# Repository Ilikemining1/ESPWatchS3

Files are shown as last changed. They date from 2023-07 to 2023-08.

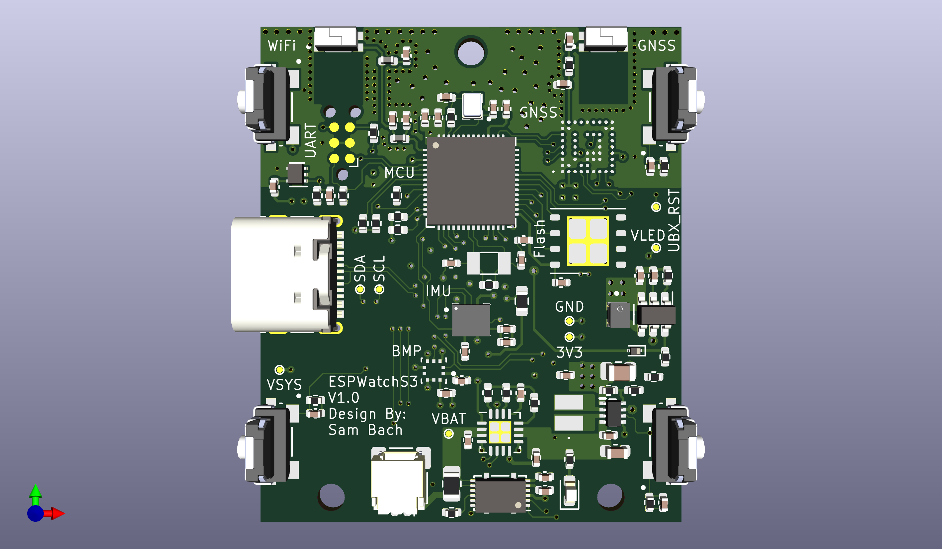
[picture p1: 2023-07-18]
PCB Outputs/ESPWatchS3 PCB Front.png

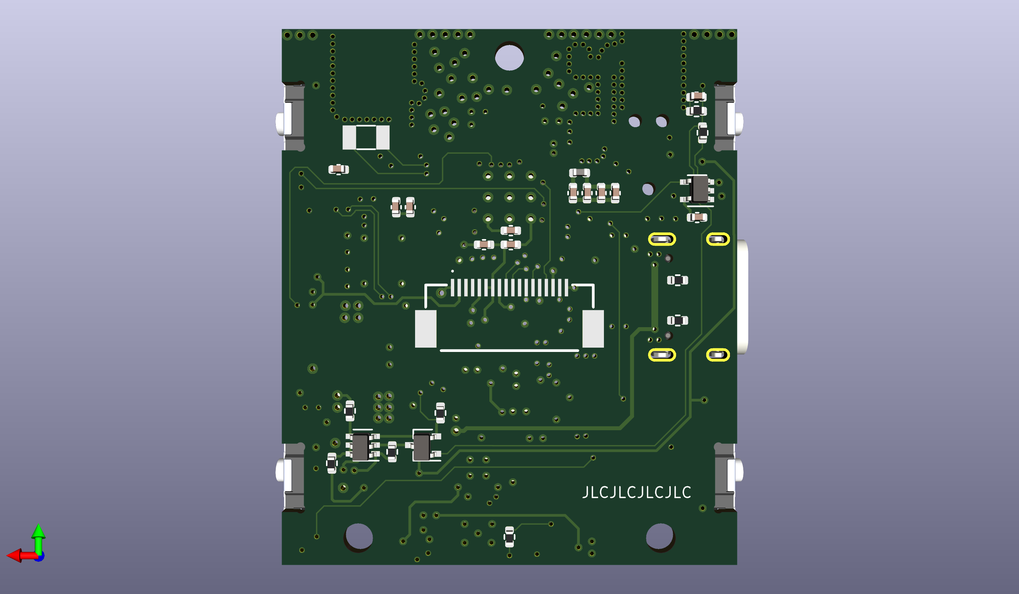
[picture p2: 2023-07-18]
PCB Outputs/ESPWatchS3 PCB Rear.png

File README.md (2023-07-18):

ESP32-S3 based Smartwatch Project
=================================

This project aims to develop an open-source smartwatch design based around an ESP32-S3 microcontroller, as it offers many useful features, such as integrated Wi-Fi, Bluetooth and 8MB of PSRAM.  This allows a watch to be designed with a minimal number of extra components beside the MCU itself.

Component Selection
-------------------

| Component | Model | Datasheet |
|---|---|---|
| MCU | ESP32-S3R8 | [ESP32-S3](https://www.espressif.com/sites/default/files/documentation/esp32-s3_datasheet_en.pdf) |
| Display | CFAF240240A3-013TN  | [CFAF240240A3-013TN ](https://www.crystalfontz.com/products/document/4754/CFAF240240A3-013TNDatasheet.pdf) |
| Barometric Pressure Sensor | BMP390 | [BMP390](https://www.bosch-sensortec.com/media/boschsensortec/downloads/datasheets/bst-bmp390-ds002.pdf) |
| IMU | ICM-42688-P | [ICM-42688-P](https://invensense.tdk.com/wp-content/uploads/2022/12/DS-000347-ICM-42688-P-v1.7.pdf) |
| GNSS Receiver | MIA-M10Q-0 | [MIA-M10Q](https://content.u-blox.com/sites/default/files/documents/MIA-M10Q_DataSheet_UBX-22015849.pdf) |
| Flash | IS25LP128F-JKLE (16MB) | [IS25WP128](https://www.issi.com/WW/pdf/25LP-WP128F.pdf) |
| | | |
| Battery Charger | BQ24075RGTR | [BQ24075](https://www.ti.com/lit/ds/symlink/bq24075.pdf) |
| Fuel Gauge | BQ27441DRZR-G1A | [BQ27441-G1](https://www.ti.com/lit/ds/symlink/bq27441-g1.pdf) |
| Battery | ASR00007 | [ASR00007](https://www.mouser.com/datasheet/2/855/ASR00007_290mAh-3078659.pdf) |
| Battery Connector | SM02B-SRSS-TB(LF)(SN) | [SM02B-SRSS-TB(LF)(SN)](https://www.jst-mfg.com/product/pdf/eng/eSH.pdf) |
| | | |
| Main SMPS | TPS631000DRLR | [TPS631000](https://www.ti.com/lit/ds/symlink/tps631000.pdf) |
| LED Driver | AP3036B | [AP3036B](https://www.diodes.com/assets/Datasheets/AP3036B.pdf) |

ESP GPIO Allocation
-------------------
| GPIO | Function |
|---|---|
| 0 | Bootloader (Strapping) FREE |
| 1 | I<sup>2</sup>C SDA |
| 2 | I<sup>2</sup>C SCL |
| 3 | JTAG Source Select (Strapping) FREE |
| 4 | Power Switch |
| 5 | User Switch 1 |
| 6 | User Switch 2 |
| 7 | User Switch 3 |
| 8 | Input Current 1 |
| 9 | Input Current 2 |
| 10 | LCD CS |
| 11 | LCD MOSI |
| 12 | LCD SCK |
| 13 | IMU INT1 |
| 14 | IMU INT2 |
| 15 | 32KHz XTAL |
| 16 | 32KHz XTAL |
| 17 | GNSS RX (UART 1 TX) |
| 18 | GNSS TX (UART 1 RX) |
| 19 | USB- |
| 20 | USB+ |
| 21 | Fuel Gauge Interrupt |
| 26 | |
| ... | Flash / PSRAM |
| 37 | |
| 38 | GNSS TX Ready |
| 39 | GNSS Timepulse |
| 40 | LCD DC |
| 41 | LCD Backlight |
| 42 | LCD TE |
| 43 | UART 0 TX |
| 44 | UART 0 RX |
| 45 | Flash Voltage Select (Strapping) FREE |
| 46 | ROM Messages (Strapping) FREE |
| 47 | SMPS Mode |
| 48 | SMPS Enable |

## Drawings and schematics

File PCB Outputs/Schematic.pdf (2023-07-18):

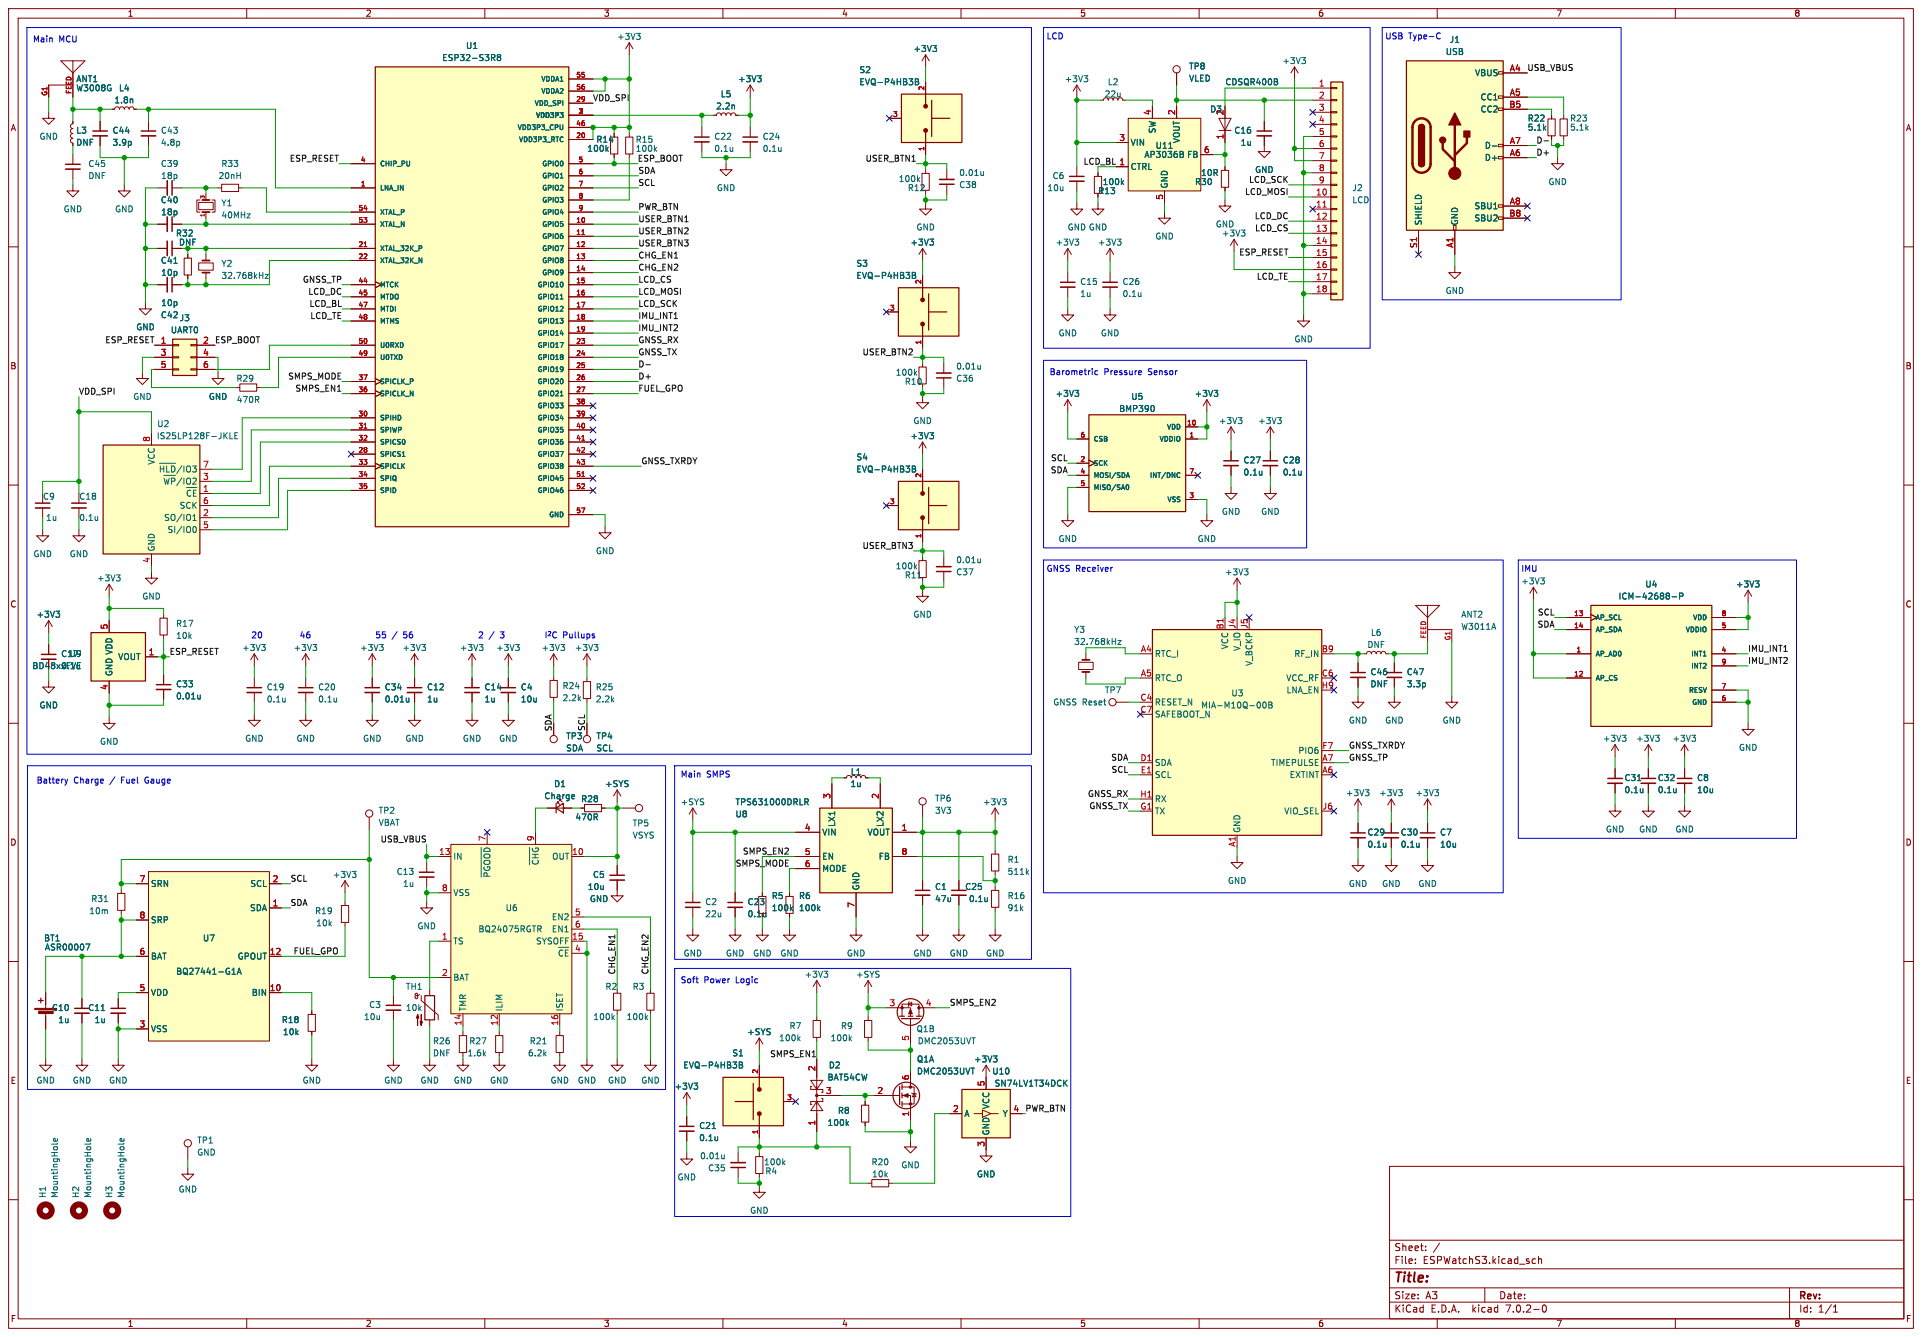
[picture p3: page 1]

4 SI/IO0 5 SCK 6 ~{HLD}/IO3 VCC 7

Battery Charge / Fuel Gauge

3 VIN 4 EN 5 MODE 6 GND

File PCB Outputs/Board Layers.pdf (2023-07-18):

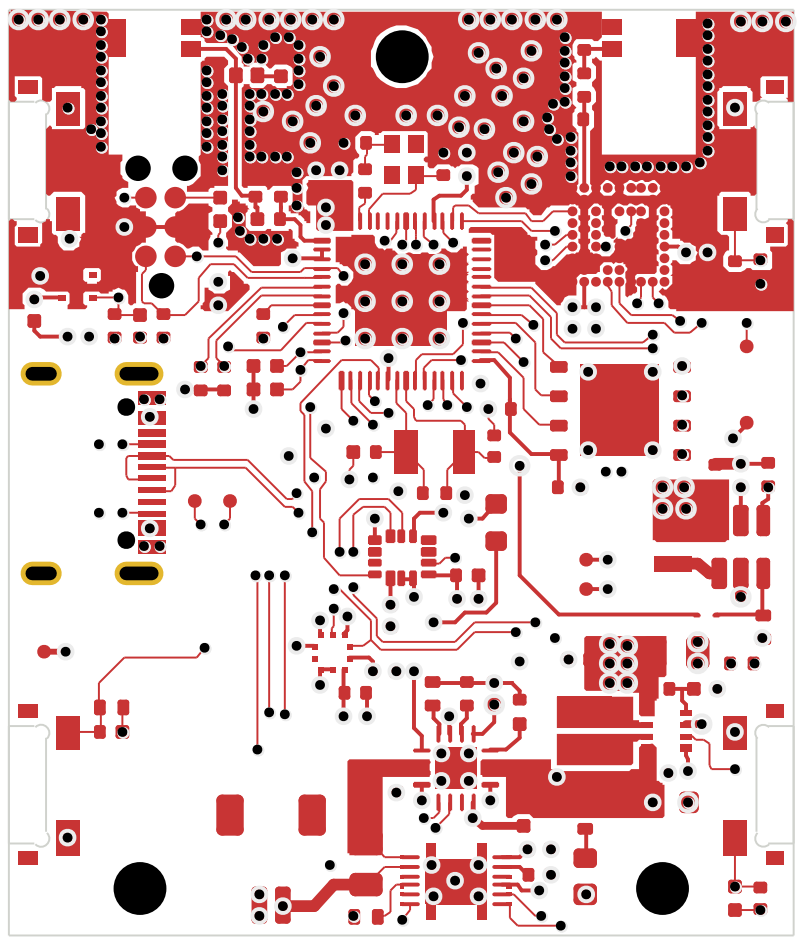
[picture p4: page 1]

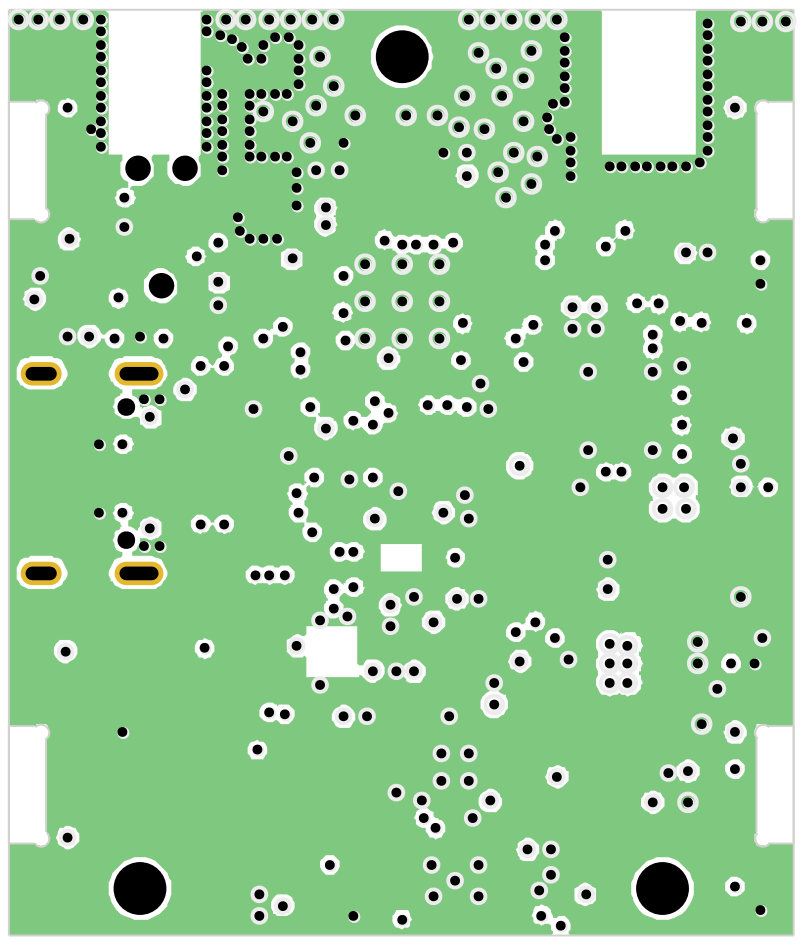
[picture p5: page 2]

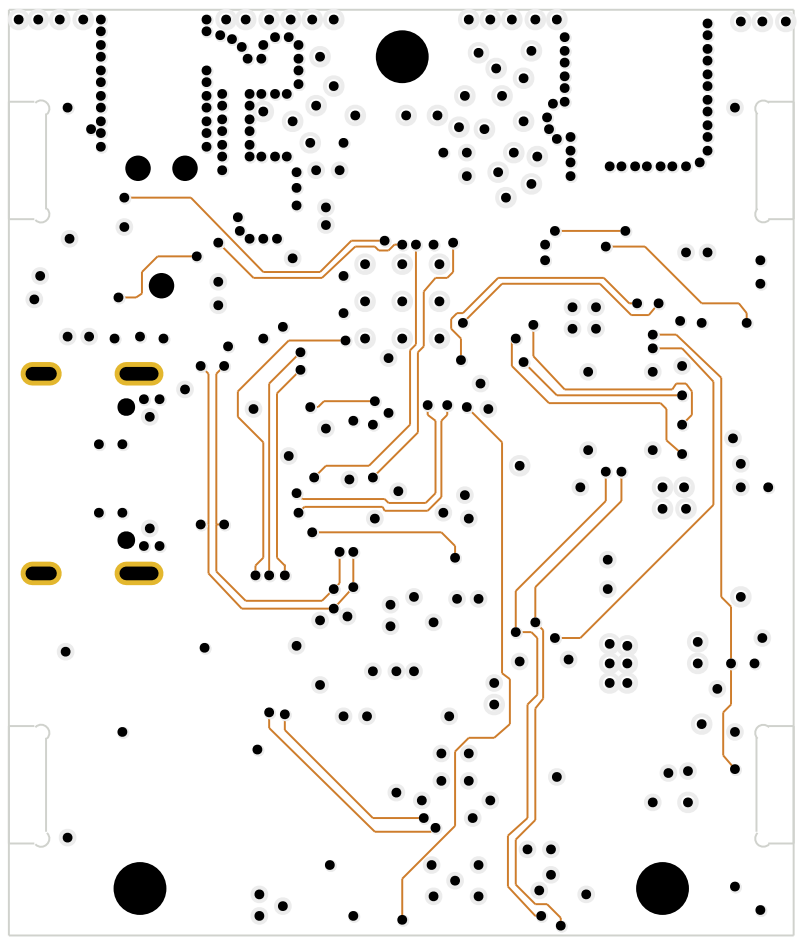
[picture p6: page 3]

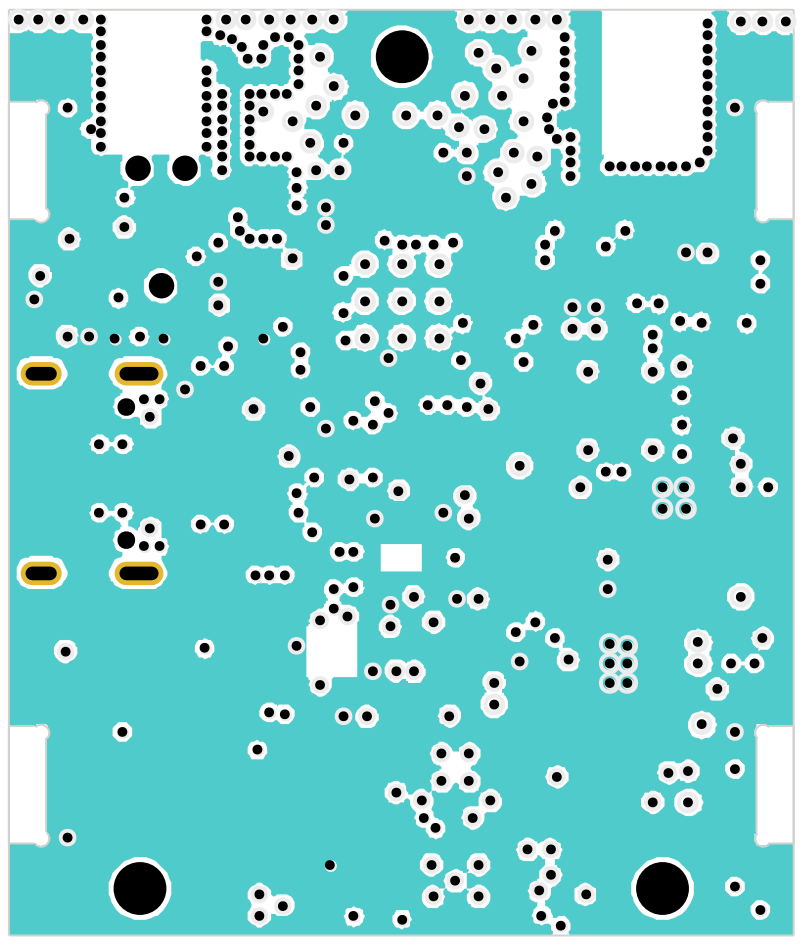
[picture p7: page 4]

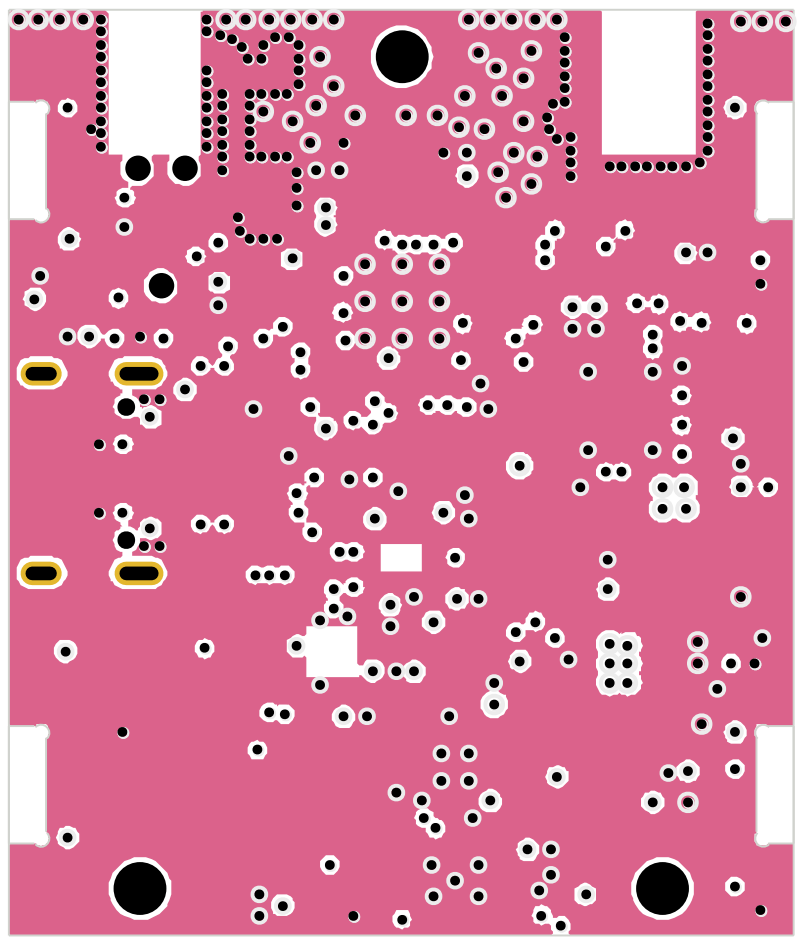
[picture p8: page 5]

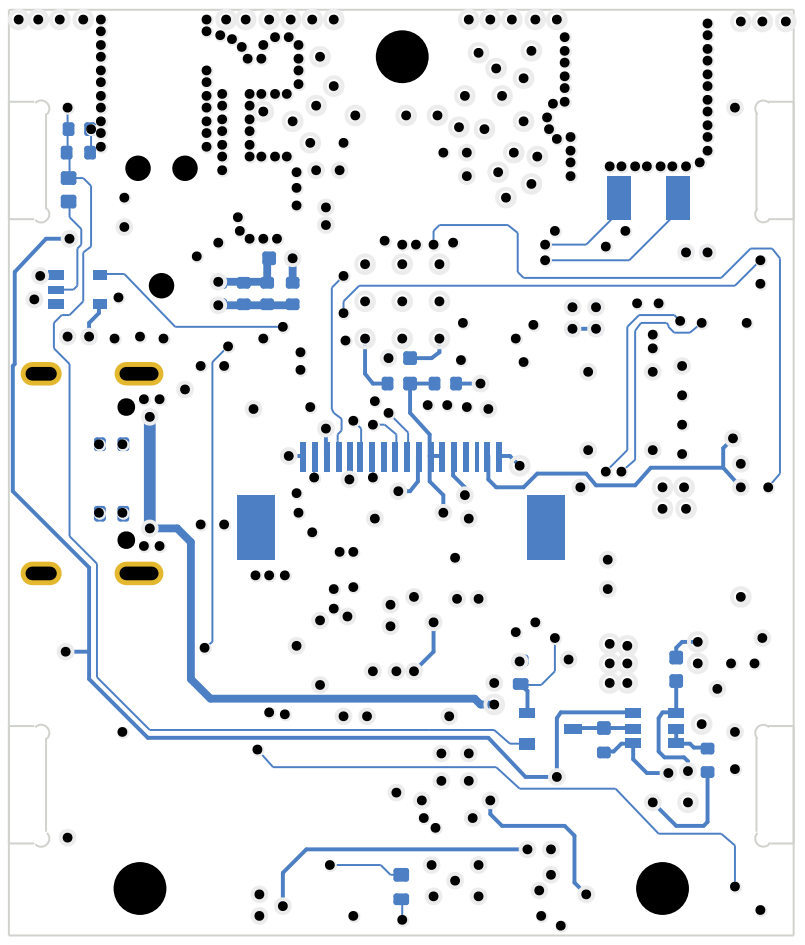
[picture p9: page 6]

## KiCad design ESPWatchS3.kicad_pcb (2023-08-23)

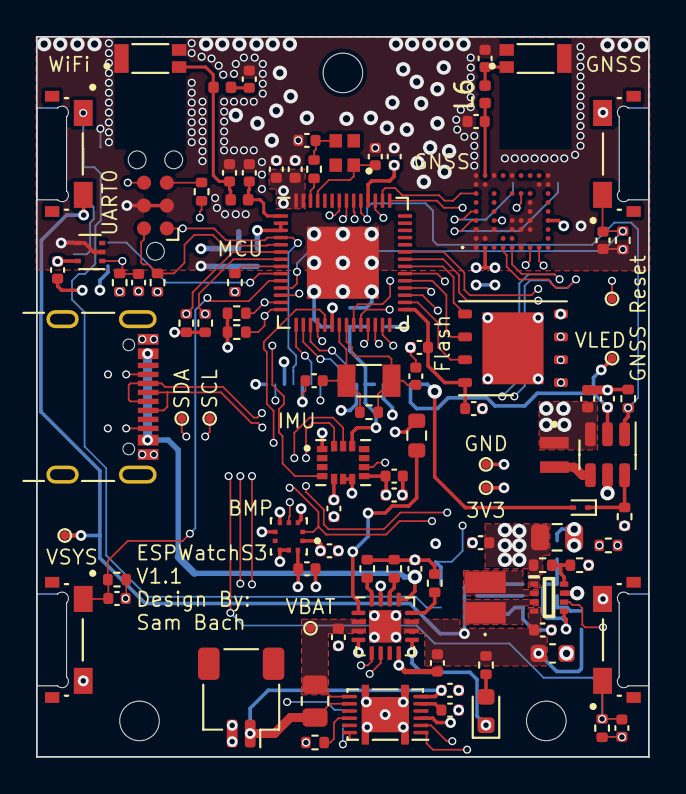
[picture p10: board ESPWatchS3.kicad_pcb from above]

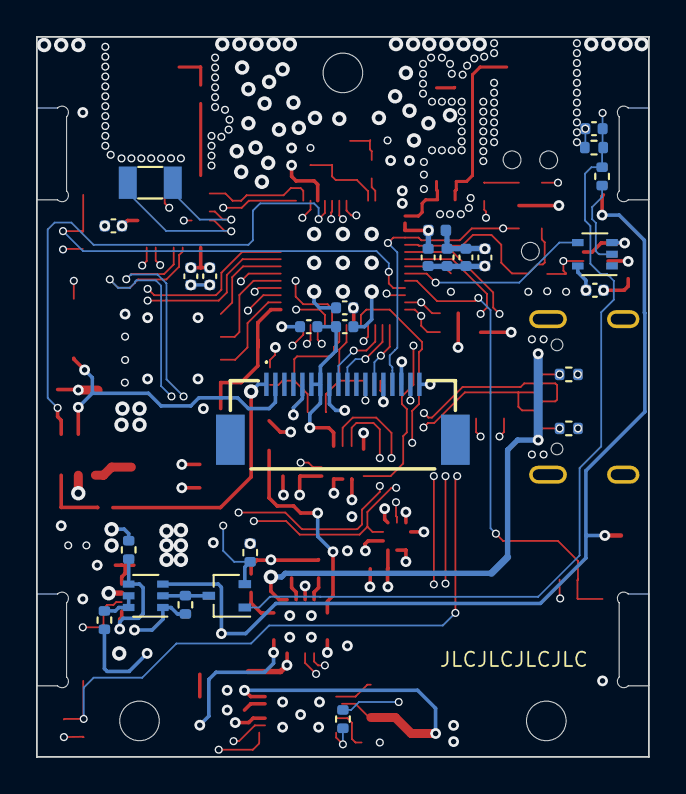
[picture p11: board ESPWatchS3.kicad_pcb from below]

Board: 6 copper layers, 34.0 x 40.0 mm, 126 parts (28 on the bottom side), 80 nets.

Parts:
ANT1: W3008C; ANTENNA_W3008C
ANT2: W3011A; ANTENNA_W3011A
BT1: ASR00007; JST_SH_SM02B-SRSS-TB_1x02-1MP_P1.00mm_Horizontal
C1: 47u; C_0805_2012Metric
C2: 22u; C_0603_1608Metric
C3, C4, C5, C6, C7, C8: 10u; C_0402_1005Metric
C9, C10, C11, C12, C13, C14, C15, C16: 1u; C_0402_1005Metric
C17, C18, C19, C20, C21, C22, C23, C24, C25, C26, C27, C28, C29, C30, C31, C32: 0.1u; C_0402_1005Metric
C33, C34, C35, C36, C37, C38: 0.01u; C_0402_1005Metric
C39, C40: 18p; C_0402_1005Metric
C41, C42: 10p; C_0402_1005Metric
C43: 4.8p; C_0402_1005Metric
C44: 3.9p; C_0402_1005Metric
C45, C46: DNF; C_0402_1005Metric
C47: 3.3p; C_0402_1005Metric
D1: Charge; LED_0603_1608Metric
D2: BAT54CW; SOT-323_SC-70
D3: CDSQR400B; D_SOD-923
H1, H2, H3: MountingHole; MountingHole_2.2mm_M2
J1: USB; USB_C_Receptacle_GCT_USB4105-xx-A_16P_TopMnt_Horizontal
J2: LCD; CS050Z18GA0
J3: UART0; Tag-Connect_TC2030-IDC-NL_2x03_P1.27mm_Vertical
L1: 1u; SRP2512TMA1R0M
L2: 22u; IND_VLS201612CX-220M-1
L3: DNF; L_0402_1005Metric
L4: 1.8n; L_0402_1005Metric
L5: 2.2n; L_0402_1005Metric
L6: 0R; L_0402_1005Metric
Q1: DMC2710UDW; SOT-363_SC-70-6
R1: 511k; R_0402_1005Metric
R2, R3, R4, R5, R6, R7, R8, R9, R10, R11, R12, R13, R14, R15: 100k; R_0402_1005Metric
R16: 91k; R_0402_1005Metric
R17, R18, R19, R20: 10k; R_0402_1005Metric
R21: 6.2k; R_0402_1005Metric
R22, R23: 5.1k; R_0402_1005Metric
R24, R25: 2.2k; R_0402_1005Metric
R26, R32: DNF; R_0402_1005Metric
R27: 1.6k; R_0402_1005Metric
R28, R29: 470R; R_0402_1005Metric
R30: 10R; R_0402_1005Metric
R31: 10m; R_0805_2012Metric
R33: 20nH; R_0402_1005Metric
S1, S2, S3, S4: EVQ-P4HB3B; SW_EVQ-P4HB3B
TH1: 10k; R_0603_1608Metric
TP1: GND; TestPoint_Pad_D0.5mm
TP2: VBAT; TestPoint_Pad_D0.5mm
TP3: SDA; TestPoint_Pad_D0.5mm
TP4: SCL; TestPoint_Pad_D0.5mm
TP5: VSYS; TestPoint_Pad_D0.5mm
TP6: 3V3; TestPoint_Pad_D0.5mm
TP7: GNSS Reset; TestPoint_Pad_D0.5mm
TP8: VLED; TestPoint_Pad_D0.5mm
U1: ESP32-S3R8; QFN-56-1EP_7x7mm_P0.4mm_EP4x4mm
U2: IS25LP128F-JKLE; WSON-8-1EP_6x5mm_P1.27mm_EP3.4x4mm
U3: MIA-M10Q-00B; MIAM10Q00B
U4: ICM-42688-P; PQFN50P300X250X97-14N
U5: BMP390; XDCR_BMP390
U6: BQ24075RGTR; VQFN-16-1EP_3x3mm_P0.5mm_EP1.8x1.8mm
U7: BQ27441-G1A; Texas_S-PDSO-N12
U8: TPS631000DRLR; SOTFL50P160X60-8N
U9: BD48xxFVE; VSOF5
U10: SN74LV1T34DCK; SOT-353_SC-70-5
U11: AP3036B; SOT-23-6
Y1: 40MHz; OSC_XRCGB40M000F1S1DR0
Y2, Y3: 32.768kHz; Crystal_SMD_3215-2Pin_3.2x1.5mm

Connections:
+3V3: C1.1, C4.1, C6.1, C7.1, C8.1, C12.1, C14.1, C15.1, C17.1, C19.1, C20.1, C21.1, C24.1, C25.1, C26.1, C27.1, C28.1, C29.1, C30.1, C31.1, C32.1, C34.1, J2.6, J2.7, J2.16, L2.1, L5.2, R1.1, R7.1, R14.2, R15.2, R17.1, R19.1, R24.1, R25.1, S2.2, S3.2, S4.2, TP6.1, U1.20 (VDD3P3_RTC), U1.46 (VDD3P3_CPU), U1.55 (VDDA1), U1.56 (VDDA2), U3.B1 (VCC), U3.J4 (V_IO), U4.1 (AP_AD0), U4.5 (VDDIO), U4.8 (VDD), U4.12 (AP_CS), U5.1 (VDDIO), U5.6 (CSB), U5.10 (VDD), U8.1 (VOUT), U9.5 (VDD), U10.5 (VCC), U11.3 (VIN)
+SYS: C2.1, C5.1, C23.1, Q1.3 (S), R9.1, R28.2, S1.2, TP5.1, U6.10 (OUT), U6.11 (OUT), U8.4 (VIN)
/CHG_EN1: R2.1, U1.13 (GPIO8), U6.6 (EN1)
/CHG_EN2: R3.1, U1.14 (GPIO9), U6.5 (EN2)
/D+: J1.A6 (D+), J1.B6 (D+), U1.26 (GPIO20)
/D-: J1.A7 (D-), J1.B7 (D-), U1.25 (GPIO19)
/ESP_BOOT: J3.2, R14.1, U1.5 (GPIO0)
/ESP_RESET: C33.1, J2.15, J3.1, R17.2, U1.4 (CHIP_PU), U9.1 (VOUT)
/FUEL_GPO: R19.2, U1.27 (GPIO21), U7.12 (GPOUT)
/GNSS_RX: U1.23 (GPIO17), U3.H1 (RX)
/GNSS_TP: U1.44 (MTCK), U3.A7 (TIMEPULSE)
/GNSS_TX: U1.24 (GPIO18), U3.G1 (TX)
/GNSS_TXRDY: U1.43 (GPIO38), U3.F7 (PIO6)
/IMU_INT1: U1.18 (GPIO13), U4.4 (INT1)
/IMU_INT2: U1.19 (GPIO14), U4.9 (INT2)
/LCD_BL: R13.1, U1.47 (MTDI), U11.1 (CTRL)
/LCD_CS: J2.13, U1.15 (GPIO10)
/LCD_DC: J2.12, U1.45 (MTDO)
/LCD_MOSI: J2.10, U1.16 (GPIO11)
/LCD_SCK: J2.9, U1.17 (GPIO12)
/LCD_TE: J2.17, U1.48 (MTMS)
/PWR_BTN: U1.9 (GPIO4), U10.4 (Y)
/SCL: R25.2, TP4.1, U1.7 (GPIO2), U3.E1 (SCL), U4.13 (AP_SCL), U5.2 (SCK), U7.2 (SCL)
/SDA: R24.2, TP3.1, U1.6 (GPIO1), U3.D1 (SDA), U4.14 (AP_SDA), U5.4 (MOSI/SDA), U7.1 (SDA)
/SMPS_EN1: D2.2, R7.2, U1.36 (SPICLK_N)
/SMPS_EN2: Q1.4 (D), R5.1, U8.5 (EN)
/SMPS_MODE: R6.1, U1.37 (SPICLK_P), U8.6 (MODE)
/USB_VBUS: C13.1, J1.A4 (VBUS), J1.A9 (VBUS), J1.B4 (VBUS), J1.B9 (VBUS), U6.13 (IN)
/USER_BTN1: C38.2, R12.1, S2.1, U1.10 (GPIO5)
/USER_BTN2: C36.2, R10.1, S3.1, U1.11 (GPIO6)
/USER_BTN3: C37.2, R11.1, S4.1, U1.12 (GPIO7)
/VDD_SPI: C9.1, C18.1, U1.29 (VDD_SPI), U2.8 (VCC)
BAT: C3.1, R31.1, TP2.1, U6.2 (BAT), U6.3 (BAT), U7.7 (SRN)
GND: ANT1.G1, ANT1.G2, ANT2.G1, ANT2.G2, BT1.2 (-), C1.2, C2.2, C3.2, C4.2, C5.2, C6.2, C7.2, C8.2, C9.2, C10.2, C11.2, C12.2, C13.2, C14.2, C15.2, C16.2, C17.2, C18.2, C19.2, C20.2, C21.2, C22.2, C23.2, C24.2, C25.2, C26.2, C27.2, C28.2, C29.2, C30.2, C31.2, C32.2, C33.2, C34.2, C35.1, C36.1, C37.1, C38.1, C39.2, C40.2, C41.2, C42.2, C43.2, C44.2, C45.2, C46.2, C47.2, J1.A1 (GND), J1.A12 (GND), J1.B1 (GND), J1.B12 (GND), J2.5, J2.8, J2.14, J2.18, J3.3, J3.4, Q1.1 (S), R2.2, R3.2, R4.2, R5.2, R6.2, R8.2, R10.2, R11.2, R12.2, R13.2, R16.2, R18.2, R21.2, R22.2, R23.2, R26.2, R27.2, R30.2, TH1.2, TP1.1, U1.57 (GND), U2.4 (GND), U2.9 (EP), U3.A1 (GND), U3.A2 (GND), U3.A3 (GND), U3.A8 (GND), U3.A9 (GND), U3.B2 (GND), U3.B8 (GND), U3.C3 (GND), U3.C9 (GND), U3.E3 (GND), U3.E4 (GND), U3.E9 (GND), U3.F1 (GND), U3.F3 (GND), U3.F4 (GND), U3.G3 (GND), U3.G4 (GND), U3.G5 (GND), U3.G6 (GND), U3.H8 (GND), U3.J8 (GND), U3.J9 (GND), U4.6 (GND), U4.7 (RESV), U5.3 (VSS), U5.5 (MISO/SA0), U5.8 (VSS), U5.9 (VSS), U6.4 (~CE), U6.8 (VSS), U6.15 (SYSOFF), U6.17 (EP), U7.3 (VSS), U7.13 (EP), U8.7 (GND), U9.2 (GND), U9.4 (GND), U10.3 (GND), U11.5 (GND)
unnamed: ANT1.FEED, C44.1, L3.2, L4.1
unnamed: ANT2.FEED, C47.1, L6.2
unnamed: BT1.1 (+), C10.1, R31.2, U7.6 (BAT), U7.8 (SRP)
unnamed: C22.1, L5.1, U1.2 (VDD3P3), U1.3 (VDD3P3)
unnamed: C35.2, D2.1, R4.1, R20.1, S1.1
unnamed: C39.1, R33.1, Y1.3
unnamed: C45.1, L3.1
unnamed: D1.2 (A), R28.1
unnamed: D1.1 (K), U6.9 (~CHG)
unnamed: D3.2 (A), J2.1
unnamed: D3.1 (K), R30.1, U11.6 (FB)
unnamed: J1.A5 (CC1), R23.1
unnamed: J1.B5 (CC2), R22.1
unnamed: C16.1, J2.2, TP8.1, U11.2 (VOUT)
unnamed: J3.5, R29.2
unnamed: J3.6, U1.50 (U0RXD)
unnamed: Q1.5 (G), Q1.6 (D), R9.2
unnamed: D2.3, Q1.2 (G), R8.1
unnamed: R15.1, U1.8 (GPIO3)
unnamed: C43.1, L4.2, U1.1 (LNA_IN)
unnamed: U1.33 (SPICLK), U2.6 (SCK)
unnamed: U1.32 (SPICS0), U2.1 (~CE)
unnamed: U1.35 (SPID), U2.5 (SI/IO0)
unnamed: U1.30 (SPIHD), U2.7 (~HLD/IO3)
unnamed: U1.34 (SPIQ), U2.2 (SO/IO1)
unnamed: U1.31 (SPIWP), U2.3 (~WP/IO2)
unnamed: R29.1, U1.49 (U0TXD)
unnamed: C42.1, R32.2, U1.22 (XTAL_32K_N), Y2.1
unnamed: C41.1, R32.1, U1.21 (XTAL_32K_P), Y2.2
unnamed: C40.1, U1.53 (XTAL_N), Y1.1
unnamed: R33.2, U1.54 (XTAL_P)
unnamed: TP7.1, U3.C4 (RESET_N)
unnamed: C46.1, L6.1, U3.B9 (RF_IN)
unnamed: U3.A4 (RTC_I), Y3.2
unnamed: U3.A5 (RTC_O), Y3.1
unnamed: R27.1, U6.12 (ILIM)
unnamed: R21.1, U6.16 (ISET)
unnamed: R26.1, U6.14 (TMR)
unnamed: TH1.1, U6.1 (TS)
unnamed: R18.1, U7.10 (BIN)
unnamed: C11.1, U7.5 (VDD)
unnamed: R1.2, R16.1, U8.8 (FB)
unnamed: L1.1, U8.3 (LX1)
unnamed: L1.2, U8.2 (LX2)
unnamed: R20.2, U10.2 (A)
unnamed: L2.2, U11.4 (SW)

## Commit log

2023-04-20 Initial design file commit
    [ESPWatchS3.kicad_pcb, ESPWatchS3.kicad_sch]
2023-04-20 Initial schematic work
    [ESPWatchS3.kicad_sch]
2023-04-21 Schematic work and component selection
    [ESPWatchS3.kicad_sch]
2023-04-22 Schematic work, power supplies and GNSS stuff
    [ESPWatchS3.kicad_sch]
2023-04-22 Update Schematic
    [ESPWatchS3.kicad_sch]
2023-04-23 Pick fuel gauge and protection IC, implemented.
    [ESPWatchS3.kicad_sch]
2023-04-23 Update README with charger selection
2023-04-23 Added connector for OLED, update README.
    [ESPWatchS3.kicad_sch]
2023-04-23 Configured Strapping Pins
    [ESPWatchS3.kicad_sch]
2023-04-25 More schematic work, added buttons
    [ESPWatchS3.kicad_sch]
2023-04-25 Update I2C Pinout
2023-04-25 Added buttons!
    [ESPWatchS3.kicad_sch]
2023-04-25 Added Status LEDs, UART Debug
    [ESPWatchS3.kicad_sch]
2023-04-25 Mostly finished schematic layout
    [ESPWatchS3.kicad_sch]
2023-04-25 Initial annotation, and added OLED VDD Jumper
    [ESPWatchS3.kicad_sch]
2023-04-25 Initial footprint assignments
    [ESPWatchS3.kicad_sch]
2023-04-25 Finish part footprint assignment
    [ESPWatchS3.kicad_sch]
2023-04-25 Partially fixed schematic symbols missing pins
    [ESPWatchS3.kicad_sch]
2023-04-25 Initial PCB settings
    [ESPWatchS3.kicad_pcb]
2023-04-25 Fixed footprints, dumped parts into PCB layout
    [ESPWatchS3.kicad_pcb, ESPWatchS3.kicad_sch]
2023-04-25 Initial PCB Stuff
    [ESPWatchS3.kicad_pcb]
2023-04-26 PCB Layout
    [ESPWatchS3.kicad_pcb]
2023-04-27 PCB Work
    [ESPWatchS3.kicad_pcb, ESPWatchS3.kicad_sch]
2023-04-27 More changes
    [ESPWatchS3.kicad_pcb, ESPWatchS3.kicad_sch]
2023-04-28 More PCB Work
    [ESPWatchS3.kicad_pcb, ESPWatchS3.kicad_sch]
2023-05-19 Almost done PCB routing
    [ESPWatchS3.kicad_pcb, ESPWatchS3.kicad_sch]
2023-05-20 PCB Fully Routed
    [ESPWatchS3.kicad_pcb]
2023-05-20 Final PCB touches
    [ESPWatchS3.kicad_pcb]
2023-05-20 Add PCB Imagery
2023-05-23 Adjust OLED connections
    [ESPWatchS3.kicad_pcb]
2023-05-25 Final changes to design for V0.1
    [ESPWatchS3.kicad_pcb]
2023-05-25 Update README with switch away from coin cell.
2023-05-25 Cleanup for Rev 1.0
    [ESPWatchS3.kicad_pcb]
2023-05-25 Update schematic with V1.0 design
    [ESPWatchS3.kicad_sch]
2023-05-26 Finish reannotation of schematic
    [ESPWatchS3.kicad_sch]
2023-05-26 Initial PCB Generation
    [ESPWatchS3.kicad_pcb]
2023-05-26 Initial PCB work for V1.0
    [ESPWatchS3.kicad_pcb]
2023-05-29 Update schematic to add mounting holes
    [ESPWatchS3.kicad_sch]
2023-06-08 Significant PCB work
    [ESPWatchS3.kicad_pcb]
2023-06-09 Even more!
    [ESPWatchS3.kicad_pcb]
2023-06-10 Even more
    [ESPWatchS3.kicad_pcb]
2023-06-12 Routing continues
    [ESPWatchS3.kicad_pcb]
2023-06-14 0 nets unrouted!
    [ESPWatchS3.kicad_pcb]
2023-07-08 Finished 40mm round PCB
    [ESPWatchS3.kicad_pcb]
2023-07-08 Schematic work
    [ESPWatchS3.kicad_sch]
2023-07-08 Remove existing PCB layout
    [ESPWatchS3.kicad_pcb]
2023-07-09 Library and schematic cleanup, revised designwork
    [ESPWatchS3.kicad_sch]
2023-07-10 Finish and reannotate schematic minus LCD BL SMPS
    [ESPWatchS3.kicad_sch]
2023-07-10 Rethought pin allocation for power use
    [ESPWatchS3.kicad_sch]
2023-07-10 Finalize schematic?
    [ESPWatchS3.kicad_sch]
2023-07-11 Re-annotated schematic
    [ESPWatchS3.kicad_sch]
2023-07-11 Finished Footprint Assignment
    [ESPWatchS3.kicad_sch]
2023-07-12 Initial PCB Work
    [ESPWatchS3.kicad_pcb, ESPWatchS3.kicad_sch]
2023-07-14 Routing work
    [ESPWatchS3.kicad_pcb, ESPWatchS3.kicad_sch]
2023-07-14 Layout continues
    [ESPWatchS3.kicad_pcb]
2023-07-14 More of the same
    [ESPWatchS3.kicad_pcb]
2023-07-15 Just 50 nets left!
    [ESPWatchS3.kicad_pcb]
2023-07-16 Cleanup work, silkscreen, file exports
    [ESPWatchS3-B_Cu.gbl, ESPWatchS3-B_Mask.gbs, ESPWatchS3-B_Paste.gbp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]
2023-07-18 Update production files
    [ESPWatchS3-B_Cu.gbl, ESPWatchS3-B_Mask.gbs, ESPWatchS3-B_Paste.gbp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]
2023-07-18 Update Readme with LED driver info
2023-07-19 Update schematic value and reexport final gerbers
    [ESPWatchS3-B_Cu.gbl, ESPWatchS3-B_Mask.gbs, ESPWatchS3-B_Paste.gbp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]
2023-08-23 Initial PCB V1.1 changes
    [ESPWatchS3.kicad_pcb, ESPWatchS3.kicad_sch]
